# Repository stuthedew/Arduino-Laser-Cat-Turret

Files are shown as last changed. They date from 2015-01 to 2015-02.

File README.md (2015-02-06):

Arduino Laser Cat Turret
========================

Arduino-based laser turret/automatic cat toy using a pan-tilt
rig (https://www.adafruit.com/products/1967) and laser diode
(https://www.adafruit.com/products/1054). Random laser path, speed
and pauses determined by homebrew Markov chain algorithm.

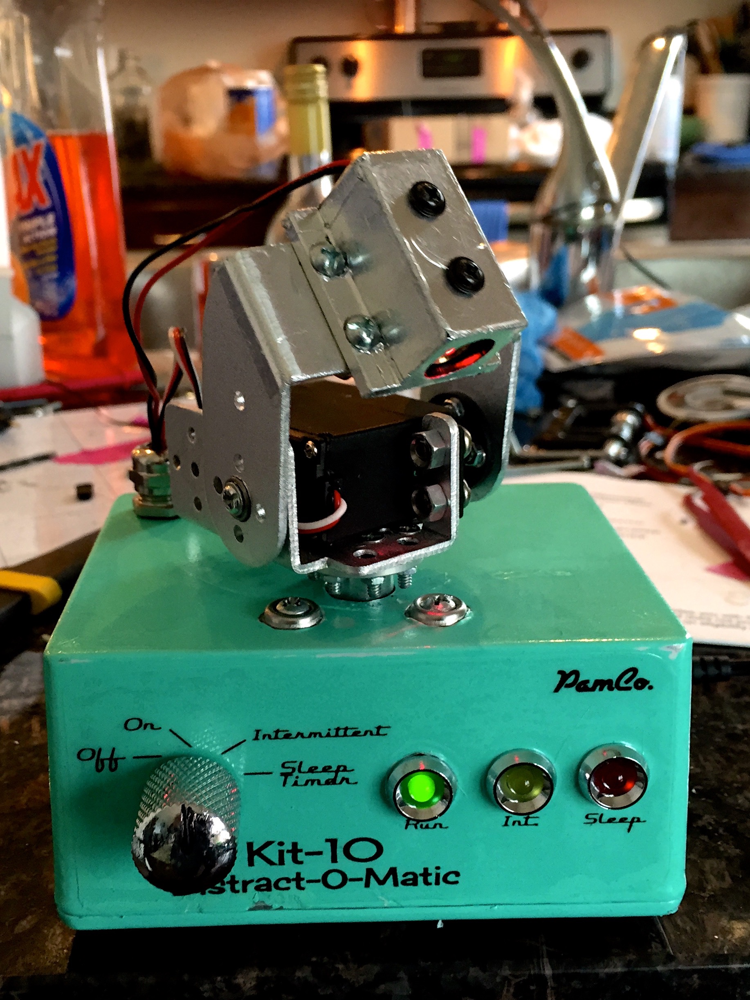
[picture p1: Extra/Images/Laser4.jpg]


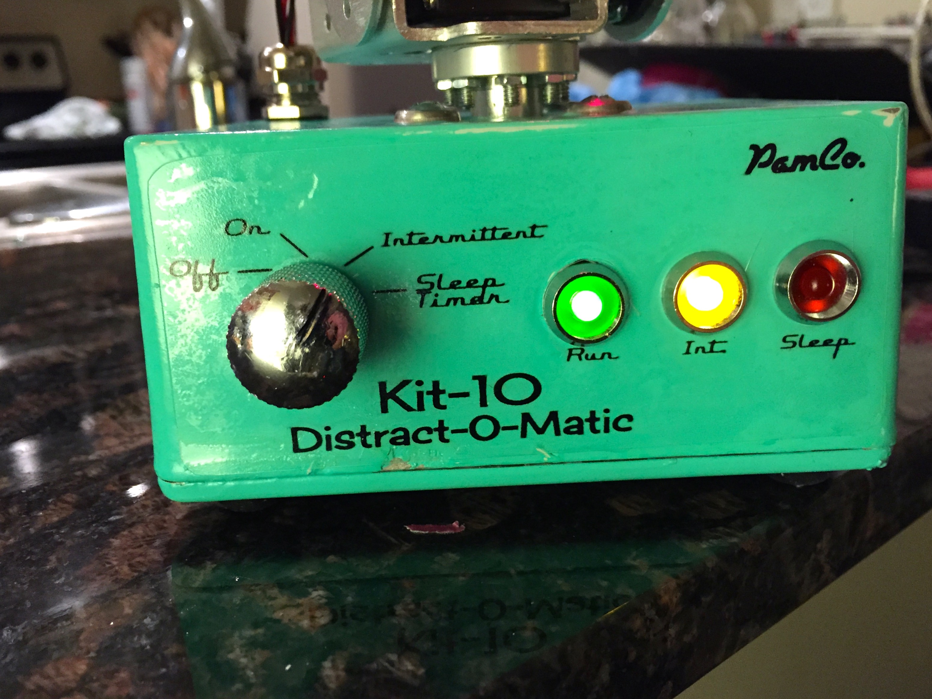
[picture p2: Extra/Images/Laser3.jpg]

(The panel text was made using QCAD and then printed (horiztonally reversed) onto [transparent inkjet paper](http://www.amazon.com/gp/product/B000XALNPI)).

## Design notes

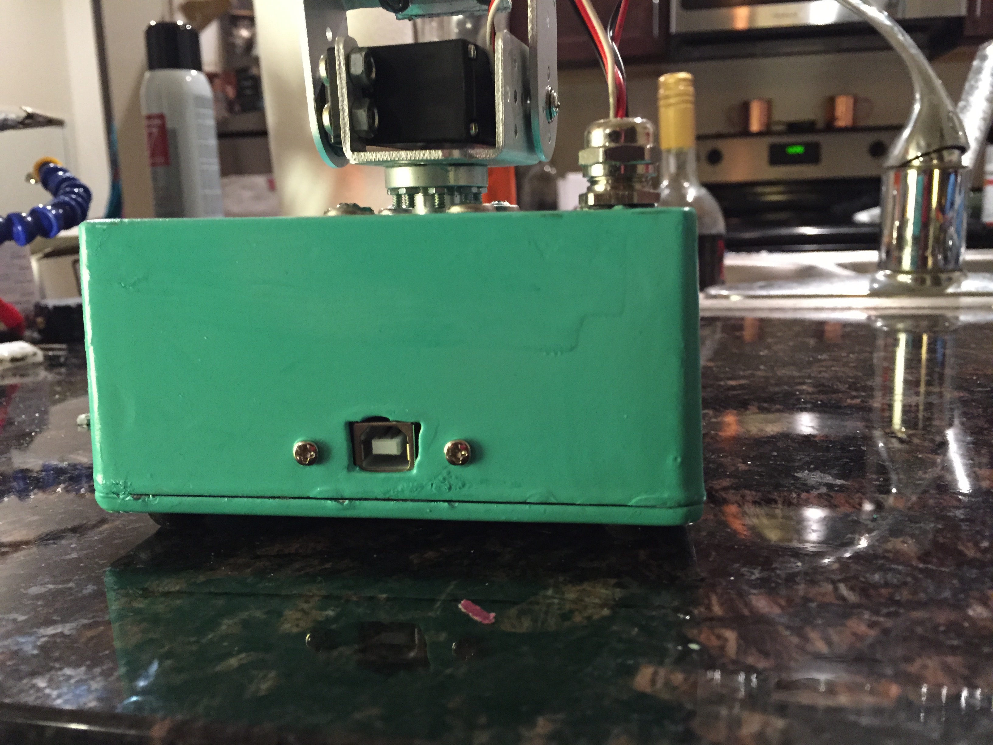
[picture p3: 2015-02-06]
Extra/Images/Laser2.jpg

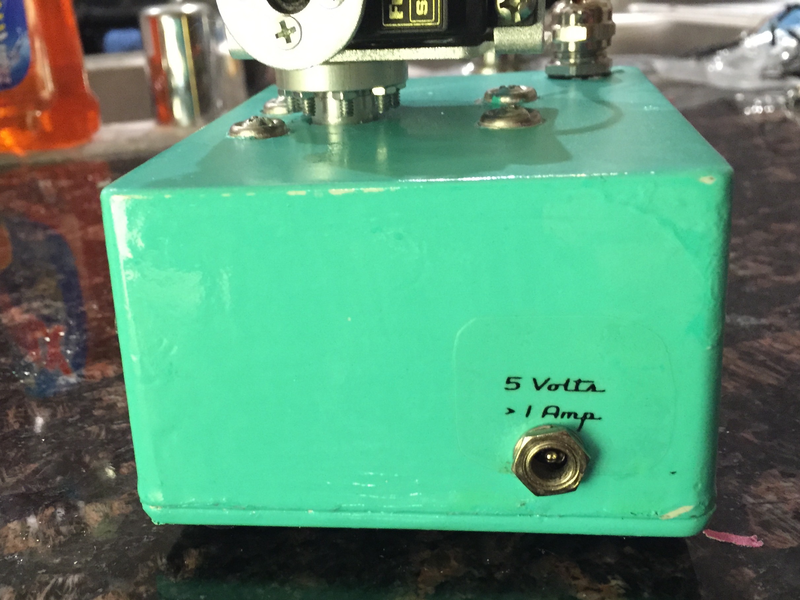
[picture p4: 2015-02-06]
Extra/Images/Laser1.jpg

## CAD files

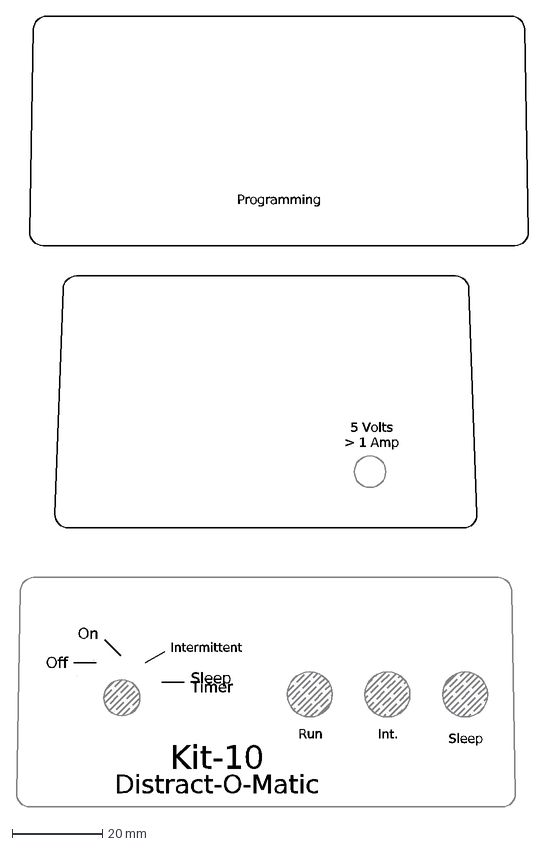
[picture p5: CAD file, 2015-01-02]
CAD Files/Dial.dxf
5 Volts > 1 Amp
Programming
Off
On
Intermittent
Sleep Timer
Run
Int.
Sleep
Kit-10
Distract-O-Matic

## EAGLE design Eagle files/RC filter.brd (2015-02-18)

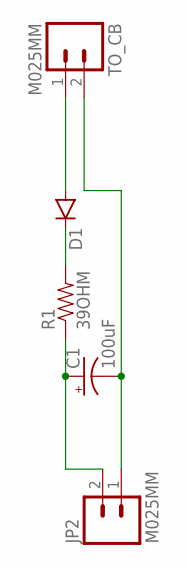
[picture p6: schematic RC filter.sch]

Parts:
C1: 100uF; EIA7343
D1: DIODESMA; SMA-DIODE
JP2: M025MM; SCREWTERMINAL-5MM-2
R1: 39OHM; 0603
TO_CB: M025MM; SCREWTERMINAL-5MM-2

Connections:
GND: C1.C (-), JP2.1, TO_CB.2
unnamed: D1.C, R1.2
V_IN: D1.A, TO_CB.1
V_OUT: C1.A (+), JP2.2, R1.1

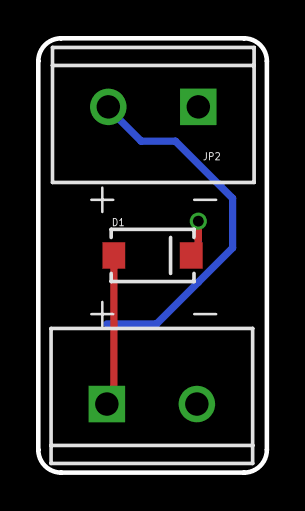
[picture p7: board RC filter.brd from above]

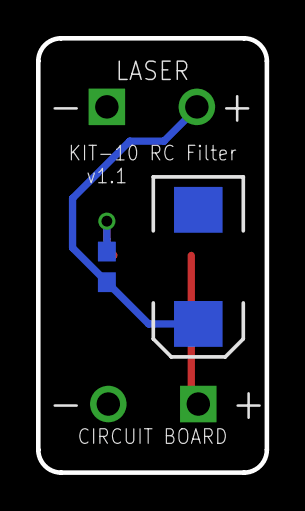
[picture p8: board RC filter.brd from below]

Board: 2 copper layers, 12.7 x 24.1 mm, 5 parts (2 on the bottom side), 4 nets.

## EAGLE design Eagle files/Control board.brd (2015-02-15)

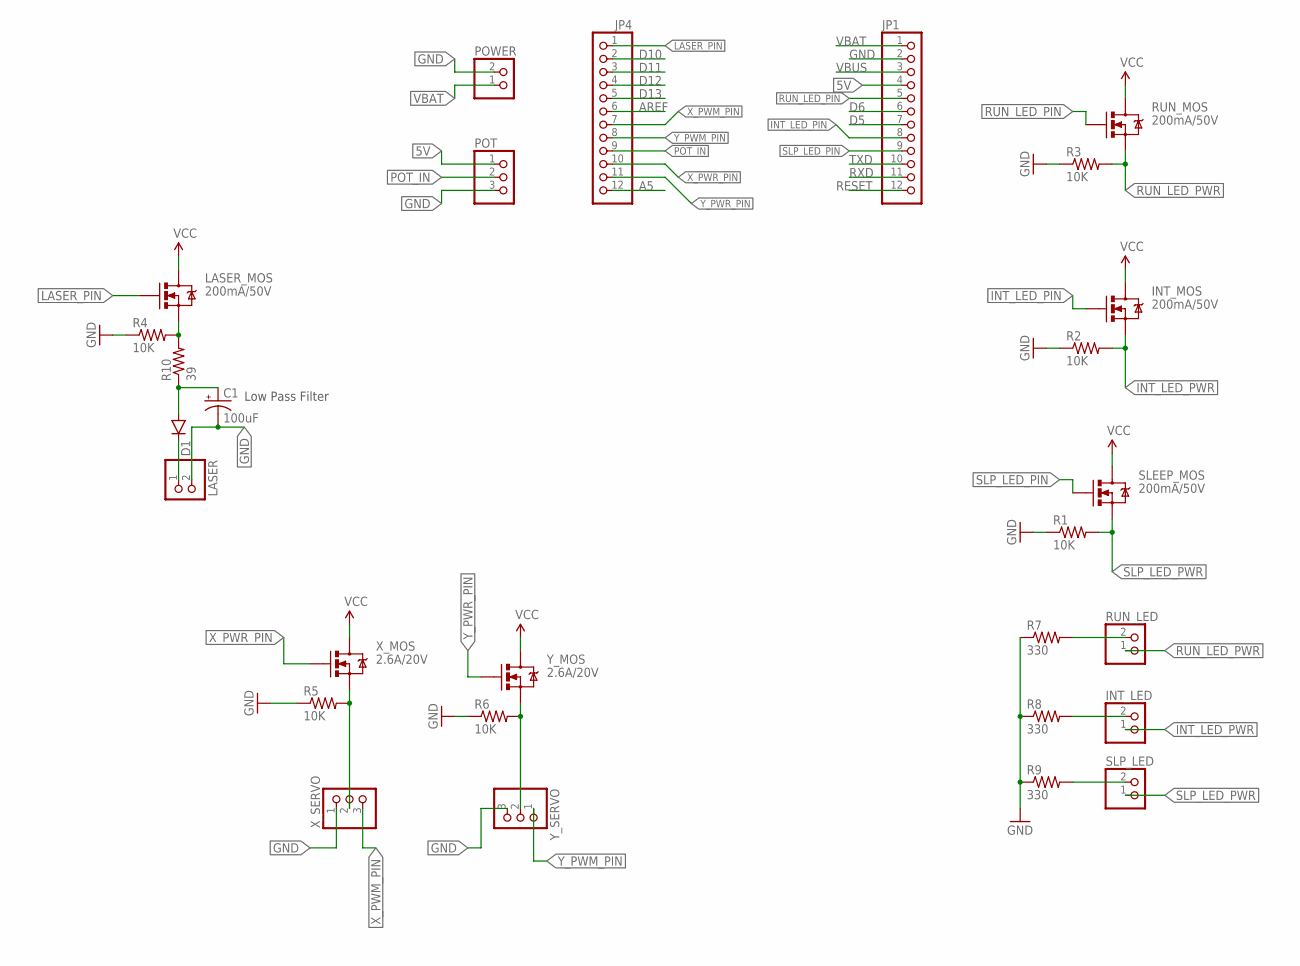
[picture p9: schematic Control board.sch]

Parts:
C1: 100uF; EIA7343
D1: DIODESOD123; SOD-123
INT_LED: JST_2PIN-SMT-RA; JST-PH-2-SMT-RA
INT_MOS: 200mA/50V; SOT23-3
JP1, JP4: PINHD-1X12-CB; 1X12-CB
LASER: JST_2PIN-SMT-RA; JST-PH-2-SMT-RA
LASER_MOS: 200mA/50V; SOT23-3
POT: JST_3PIN; JSTPH3
POWER: JST_2PIN-SMT-RA; JST-PH-2-SMT-RA
R1, R2, R3, R4, R5, R6: 10K; 0603-RES
R7, R8, R9: 330; 0603-RES
R10: 39; 0603-RES
RUN_LED: JST_2PIN-SMT-RA; JST-PH-2-SMT-RA
RUN_MOS: 200mA/50V; SOT23-3
SLEEP_MOS: 200mA/50V; SOT23-3
SLP_LED: JST_2PIN-SMT-RA; JST-PH-2-SMT-RA
X_MOS: 2.6A/20V; SOT23-3
X_SERVO: PINHD-1X3; 1X03
Y_MOS: 2.6A/20V; SOT23-3
Y_SERVO: PINHD-1X3; 1X03

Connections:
5V: JP1.4, POT.1
A5: JP4.12
AREF: JP4.6
D5: JP1.7
D6: JP1.6
D10: JP4.2
D11: JP4.3
D12: JP4.4
D13: JP4.5
GND: C1.C (-), JP1.2, LASER.2 (1), POT.3, POWER.2 (1), R1.1, R2.1, R3.1, R4.1, R5.1, R6.1, R7.1, R8.1, R9.1, X_SERVO.1, Y_SERVO.3
INT_LED_PIN: INT_MOS.1 (G), JP1.8
INT_LED_PWR: INT_LED.1 (2), INT_MOS.2 (S), R2.2
LASER_PIN: JP4.1, LASER_MOS.1 (G)
LASER_PWR: LASER_MOS.2 (S), R4.2, R10.2
unnamed: C1.A (+), D1.A, R10.1
unnamed: D1.C, LASER.1 (2)
unnamed: R6.2, Y_MOS.2 (S), Y_SERVO.2
unnamed: R5.2, X_MOS.2 (S), X_SERVO.2
unnamed: R7.2, RUN_LED.2 (1)
unnamed: INT_LED.2 (1), R8.2
unnamed: R9.2, SLP_LED.2 (1)
POT_IN: JP4.9, POT.2
RESET: JP1.12
RUN_LED_PIN: JP1.5, RUN_MOS.1 (G)
RUN_LED_PWR: R3.2, RUN_LED.1 (2), RUN_MOS.2 (S)
RXD: JP1.11
SLP_LED_PIN: JP1.9, SLEEP_MOS.1 (G)
SLP_LED_PWR: R1.2, SLEEP_MOS.2 (S), SLP_LED.1 (2)
TXD: JP1.10
VBAT: INT_MOS.3 (D), JP1.1, LASER_MOS.3 (D), POWER.1 (2), RUN_MOS.3 (D), SLEEP_MOS.3 (D), X_MOS.3 (D), Y_MOS.3 (D)
VBUS: JP1.3
X_PWM_PIN: JP4.7, X_SERVO.3
X_PWR_PIN: JP4.10, X_MOS.1 (G)
Y_PWM_PIN: JP4.8, Y_SERVO.1
Y_PWR_PIN: JP4.11, Y_MOS.1 (G)

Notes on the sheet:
Low Pass Filter

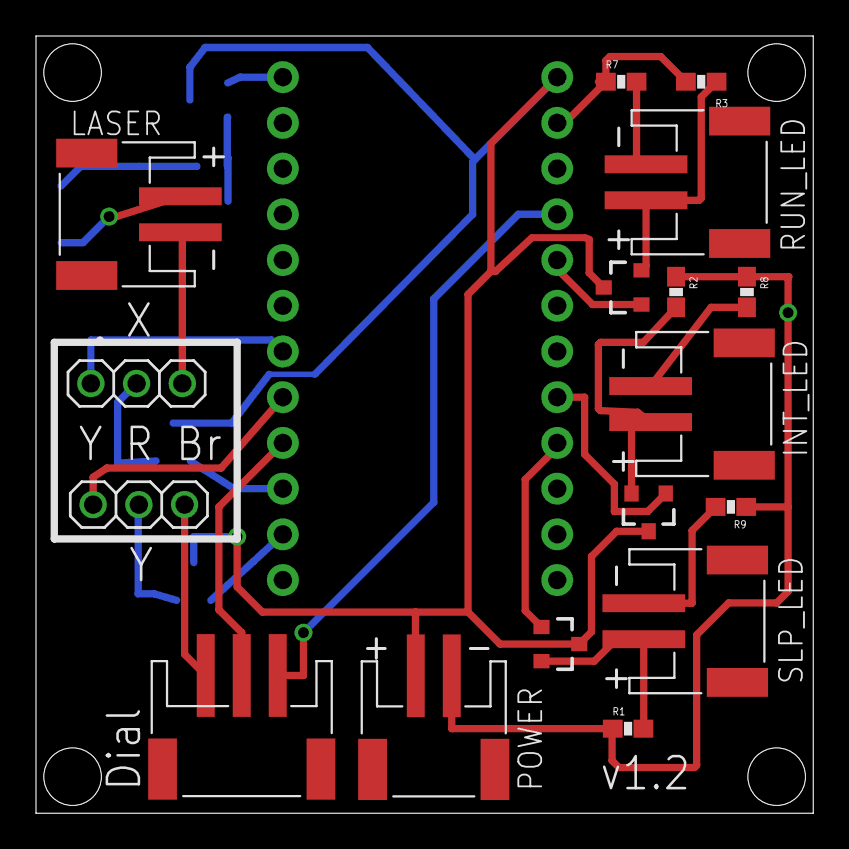
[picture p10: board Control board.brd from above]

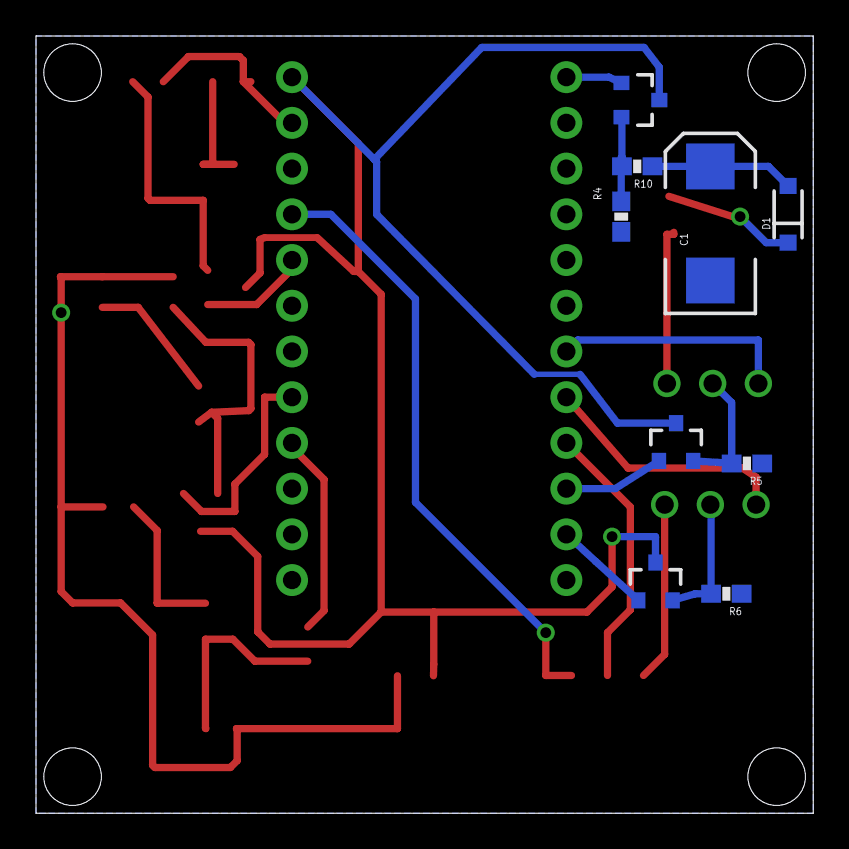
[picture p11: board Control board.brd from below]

Board: 2 copper layers, 43.2 x 43.2 mm, 28 parts (9 on the bottom side), 23 nets.

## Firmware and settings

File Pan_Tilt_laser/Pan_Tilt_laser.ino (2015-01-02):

/**************************************************************************/
/*!
@file     Pan_Tilt__laser.ino
@author   Stuart Feichtinger
@license  MIT (see license.txt)

Main program running an automatic laser-turret cat toy using a pan-tilt
rig (https://www.adafruit.com/products/1967) and laser diode
(https://www.adafruit.com/products/1054). Random laser path, speed
and pauses determined by homebrew Markov chain algorithm.


@section  HISTORY
v1.0.0 - First release
v1.1.0 - Added Markov-based speed control
v1.2.0 - Added Markov-based pause length/frequency
v1.2.1 - Added Heartbeat during pause
v1.3.0 - Added laser shake to enhance cat enjoyment
v1.3.1 - Changed probability polling frequency to once a second
v1.4.0 - Added ON/OFF Missile Switch from Sparkfun
v1.5.0 - Added scheduler and gaussian library for random values
v1.5.1 - Converted speed and direction function to scheduled task
v1.6.0 - Switched Markov speed change to Markov handler using circuler
linked list.
v1.6.1 - Switched Markov state to Markov handler
v1.7.0 - Moved control of timing to master Pan-Tilt Class
v1.8.0 - Switched to a state-machine model.
v1.9.0 - Final Version
v1.9.1 - Tweaked minimum Y servo value
v1.9.2 - Fixed bug where pauseTask was still enabled when off.
*/
/**************************************************************************/

#include "panTilt_config.h"
#include "stuPanTilt.h"
#include <Time.h>
#include <Servo.h>
#include "stuMarkov.h"
#include "stuLaser.h"
#include "stu_scheduler.h"
#include "stu_gauss.h"
#include <Gaussian.h>
#include "stu_dial.h"


#define MIN_LOOP_TIME 0


int markovShakeState = 1;
int changeVal;

LinkedMarkov lmSpeed;
LinkedMarkov lmShake;
LinkedMarkov lmPause;

PanTilt panTilt( SERVO_X_PIN, SERVO_Y_PIN );


Task pauseTask(&pauseCB);
Task updateMarkovTask(&updateMarkov, 750, 1);

void updateMarkov(){
  changeVal = lmSpeed.getNextValue();
  markovShakeState = lmShake.getNextValue();
  updateMarkovTask.enable();

}

//halt laser at certain spot for a few moments at this time
void setNextPauseTime(unsigned long avg_sec_to_pause=15, double variance=6){

  unsigned long temp = gauss.gRandom(avg_sec_to_pause, variance)*1000;

  #ifdef SERIAL_DEBUG
  #ifdef TIME_DEBUG
  MY_SERIAL.print(F("Next pause in "));
  MY_SERIAL.print(temp/1000);
  MY_SERIAL.println(F(" seconds.\n"));
  #endif
  #endif

  pauseTask.setInterval(temp);
  pauseTask.enable();

}

void offCB(){

  pauseTask.disable();

}

void runCB(){

  #ifdef SERIAL_DEBUG
  MY_SERIAL.println(F("RUN CALLBACK"));
  #endif

  setNextPauseTime();

}

void restCB(){

  #ifdef SERIAL_DEBUG
  MY_SERIAL.println(F("REST CALLBACK"));
  #endif

  return;
}


void pauseCB(){

  pauseTask.disable();

  #ifdef SERIAL_DEBUG
  MY_SERIAL.println(F("PAUSE CALLBACK"));
  #endif

  panTilt.pause( markovPause(), !!(random()%4) );

  setNextPauseTime();

}

void panTiltCB(){

  #ifdef SERIAL_DEBUG
  MY_SERIAL.println(F("Main Sketch PanTilt Callback!!!! "));
  #endif


  panTilt.callback();

}

void setup() {


  #ifdef SERIAL_DEBUG
  MY_SERIAL.begin(BAUD_RATE);
  MY_SERIAL.println(F("setup starting..."));
  #endif

  panTilt.begin();
  panTilt.setStateCallback(STATE_OFF, &offCB);
  panTilt.setStateCallback(STATE_RUN, &runCB);
  panTilt.setStateCallback(STATE_REST, &restCB);

  Task* taskPtr = panTilt.getTaskPtr();

  taskPtr->changeCallback(panTiltCB);


  //        addLinkToBack(speed, previous_state_probability, next_state_probability)
  lmSpeed.addLinkToBack( 1,  5, 35 ); // Slow
  //                           ^  ||
  //                           |  \/
  lmSpeed.addLinkToBack( 2, 25, 35 ); // Med
  //                           ^  ||
  //                           |  \/
  lmSpeed.addLinkToBack( 3, 35, 25 ); // Fast
  //                           ^  ||
  //                           |  \/
  //                          | Slow |


  //        addLinkToBack(state, previous_state_probability, next_state_probability)
  lmShake.addLinkToBack( 1,  0, 2 ); // No shake
  //                           ^  ||
  //                           |  \/
  lmShake.addLinkToBack( 2, 40, 0 ); // Shake

  randomSeed(analogRead(5));


  scheduler.addEvent(&pauseTask);
  scheduler.addEvent(&updateMarkovTask);



  #ifdef SERIAL_DEBUG
  MY_SERIAL.println(F("setup complete"));
  #endif

  setNextPauseTime();

}


void loop(){


  #ifdef SERIAL_DEBUG
  MY_SERIAL.println(panTilt.getState());
  #endif


  if( panTilt.getState() == STATE_RUN ){
    if(!pauseTask.enabled()){
      pauseTask.enable();

    }

    panTilt.posX.angle = getDeltaPosition(&panTilt.posX, changeVal, DIRECTION_CHANGE_PROBABILITY) + panTilt.posX.angle;
    panTilt.posY.angle = getDeltaPosition(&panTilt.posY, changeVal, DIRECTION_CHANGE_PROBABILITY) + panTilt.posY.angle;


    if(markovShakeState == 2){
      panTilt.shake();
    }
  }

  else if(pauseTask.enabled()){


  }
  scheduler.run();
  panTilt.update();
  delay(5);

}


int getMarkovDirection(panTiltPos_t *pt, int changeProb){

  int prob = changeProb;

  if(pt->dir == 0){
    pt->dir = 1;
  }

  if((pt->dir == 1 && pt->angle >= pt->midAngle) || (pt->dir == -1 && pt->angle <= pt->midAngle)){
    prob += abs(pt->midAngle - pt->angle) * max(pt->probOffset, 1);

  }

  if(random(1001) <= prob << 1 || (pt->angle >= pt->maxAngle && pt->dir == 1) || pt->angle <= pt->minAngle && pt->dir == -1){
    pt->dir *= -1;
  }
  return pt->dir;
}


int getDeltaPosition(panTiltPos_t *pt, int funcChangeVal, int changeProb){

  int tempVal = getMarkovDirection(pt, changeProb);

  tempVal *= funcChangeVal;

  return tempVal;

}


int markovPause(){
  int val = random(101);

  if(val < 25){
    return random(1500, 2000);
  }
  else if(val < 90){
    return random(1000, 1500);
  }
  else{
    return random(500, 750);
  }

}

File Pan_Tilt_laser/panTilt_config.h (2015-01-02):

#pragma once

#include "Arduino.h"


#define EMBED


//#define SERIAL_DEBUG


#ifdef SERIAL_DEBUG
  #define BAUD_RATE 9600
#endif

#define DIRECTION_CHANGE_PROBABILITY 15


// Servo pins
#define X_PWR_PIN   A3
#define Y_PWR_PIN   A4
#define SERVO_X_PIN A0    // PWM Pins
#define SERVO_Y_PIN A1

//LED power pins
#define POWER_PIN 8 // Power lED pin
#define CONT_PIN  4 // Continuous LED pin
#define INT_PIN   3 // Intermittent LED pin

#define LASER_PIN 9

#define DIAL_PIN A2


#ifdef SERIAL_DEBUG

#define MY_SERIAL Serial


#endif

// Global Run Mode enum
typedef enum {
  MODE_OFF = 0      ,
  MODE_CONTINUOUS   ,
  MODE_INTERMITTENT ,
  MODE_SLEEP
}runmode_e;

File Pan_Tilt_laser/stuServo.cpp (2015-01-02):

/**************************************************************************/
/*!
@file     stuServo.cpp
@author   Stuart Feichtinger
@license  MIT (see license.txt)

Augmented servo library based off of Arduino Servo library. Adds maximum
and minimum angles, and prevents servo from going past them.


@section  HISTORY
v0.0.1 - First release
v0.0.2 - Switched write to writeMicroseconds to allow maximal servo
rotation.
v0.0.3 - Added 5 microsecond delay after wake to allow capacitors to charge.

*/
/**************************************************************************/

#include "stuServo.h"


void StuServo::setPowerPin( uint8_t powerPin ){

  _powerPin = powerPin ;
  pinMode( _powerPin, OUTPUT ) ;
  digitalWrite( _powerPin, HIGH ) ;

}


void StuServo::setCalibration( int min, int max ){
  _position.min = min;
  _position.max = max;

}

void StuServo::pause( void ){
  digitalWrite( _powerPin, LOW ) ;
}

void StuServo::wake( void ){
  digitalWrite( _powerPin, HIGH ) ;
  delay(10);
}


void StuServo::stuWrite( int position ){
  int curPos = read();
  int newPos;


  if( position < _position.min ){
    newPos = _position.min ;

  }
  else if( position > _position.max ){

    newPos = _position.max ;
  }
  else{

    newPos =  position ;
  }

  int diff = newPos - curPos;
  int sign = 1;
  if( diff < 0){
    sign = -1;
    diff *= sign;
  }

  while( curPos != newPos ){
    write( curPos );
    curPos += sign;
    delay(1);
  }


}


int StuServo::getMin( void ) const {
  return _position.min ;
}


int StuServo::getMax( void ) const {
  return _position.max ;
}

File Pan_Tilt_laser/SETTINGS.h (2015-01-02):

#pragma once/*<=DON'T TOUCH!!!!!!!*/
/**************************************************************************/
/*!                   ****Customizable Settings****

Use this file to change the laser settings (e.g. the amount of time the
laser runs before shutting off in sleep mode).


                      ****EDIT THIS FILE ONLY****
/**************************************************************************/





/**************************************************************************/
/***********************Continuous Mode Settings***************************/
/************************* (ON => forever) ********************************/
/**************************************************************************/
/*                    (General purpose. Always on.)                       */
/* Settings:                                                              */
/*                                NONE                                    */
/*                                                                        */
/**************************************************************************/


/**************************************************************************/
/***********************INTERMITTENT Mode Settings*************************/
/********************* (ON => OFF => ON => REPEAT) ************************/
/**************************************************************************/
/*               (Good for when the kitty is home alone)                  */
/*SETTINGS:                                                               */
/*                                                                        */
/* MINUTES the laser stays ON in intermittent mode for each cycle.        */
/*------------------------------------------------------------------------*/
  #define INTERMITTENT_ON_TIME   15 /*<=========== CHANGE ME (Default=15) */
/*------------------------------------------------------------------------*/
/*                                                                        */
/* MINUTES the laser stays OFF in intermittent mode for each cycle.       */
/*------------------------------------------------------------------------*/
  #define INTERMITTENT_OFF_TIME  60 /*<=========== CHANGE ME (Default=60) */
/*------------------------------------------------------------------------*/
/*                                                                        */
/**************************************************************************/


/**************************************************************************/
/***************************SLEEP Mode Settings****************************/
/************************ (ON => OFF => FOREVER) **************************/
/**************************************************************************/
/*       (Good for distracting a kitty when you want to go to sleep)      */
/* SETTINGS:                                                              */
/*                                                                        */
/* MINUTES the laser stays ON before turning OFF FOREVER.                 */
/* (You must change mode with dial to restart laser.)                     */
/*------------------------------------------------------------------------*/
  #define MINUTES_BEFORE_SLEEP    30 /*<=========== CHANGE ME (Default=30)*/
/*------------------------------------------------------------------------*/
/*                                                                        */
/**************************************************************************/



#define SERVO_MIN_X_AXIS 30
#define SERVO_MAX_X_AXIS 110

#define SERVO_MIN_Y_AXIS    110
#define SERVO_MAX_Y_AXIS    140


#define LASER_MIDPOINT_OFFSET_X 0
#define LASER_MIDPOINT_OFFSET_Y 0
#define LASER_PROBABILITY_X     0
#define LASER_PROBABILITY_Y     5

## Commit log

2014-10-14 Added check when switching directions.
    Only switch direction if past max/min range AND direction going away
    from normal range.
2014-10-14 Increased delay to allow servo movement.
2014-10-14 Revert "Clean up"
    This reverts commit 1cc41362a7edf90dbaecc19a8334832e626d1877.
    [Pan_Tilt_laser.ino]
2014-10-15 Added Heartbeat pulse and fixed value overflow
    [Pan_Tilt_laser.ino]
2014-10-15 Fixed typo in rollover handling
    [Pan_Tilt_laser.ino]
2014-10-16 Added delay back between servos and clean up
2014-10-19 Added laser Shake
2014-10-25 Added switch code
2014-10-26 Added switch class
2014-10-26 Added starting delay for stability
    [Pan_Tilt_laser.ino]
2014-10-26 Added starting servo centering
2014-10-26 Changed analog read pin for random seed
2014-10-28 Switched speed/direction control to scheduler
2014-11-12 Switched #ifdef #define to #pramga once
2014-11-12 Fixed sleep/switch bug #2
    Program now returns from sleep mode once switch is off and resumes when
    switch is turned on again.
    [Pan_Tilt_laser.ino]
2014-11-14 fixed compiling error due old variables.
    [Pan_Tilt_laser.ino]
2014-11-14 Partial conversion to custom namespace
    Still problems with stuPanTilt namespace use breaking things.
    [Pan_Tilt_laser.ino, stuLaser.cpp, stuPanTilt.cpp]
2014-12-25 Added include to Arduino.h
2015-01-02 Merge branch 'Leah'
    Conflicts:
    Pan_Tilt_laser/Pan_Tilt_laser.ino
    Pan_Tilt_laser/stuServo.cpp
    [Dial.dxf, Leah Box.dxf, Leah board.brd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]
2015-02-06 Removed unused file
    [Leah Box.dxf]
2015-02-06 Added board version number
    [Leah board.brd]
2015-02-06 Tweaked Board
2015-02-06 Changed file names
    [Control board.brd, Control board.sch]
2015-02-15 added reverse diode protection on laser
    [Control board.brd, Control board.sch]
2015-02-18 Changed screw terminal to 5.08 mm layout
    Bumped board to v1.1
    [RC filter.brd, RC filter.sch]

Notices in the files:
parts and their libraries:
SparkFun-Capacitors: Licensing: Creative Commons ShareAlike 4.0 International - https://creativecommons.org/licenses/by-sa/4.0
